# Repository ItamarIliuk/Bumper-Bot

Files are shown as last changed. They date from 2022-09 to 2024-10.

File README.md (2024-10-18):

[][linkedin-url]
[][udemy-url]

<p align="center">
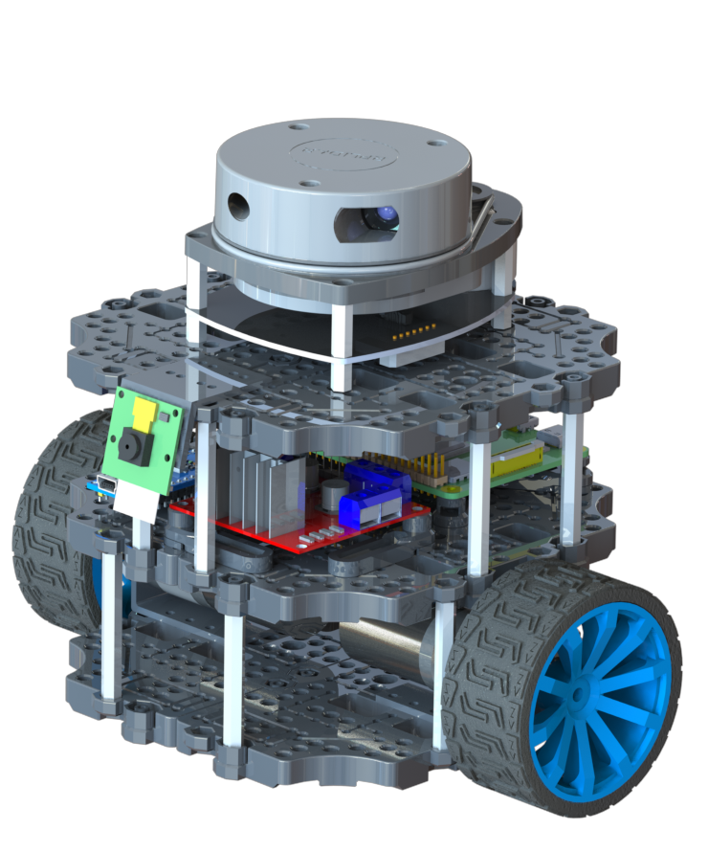
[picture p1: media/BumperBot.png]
  
</p>

Bumperbot is an open-source 3D printed self-driving robot powered by ROS 2. Its simple design and low cost make it an excellent learning platform, featured in the following online courses:
* [Self Driving and ROS 2 - Learn by Doing! Odometry & Control
](https://www.udemy.com/course/self-driving-and-ros-2-learn-by-doing-odometry-control/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)
* [Self Driving and ROS 2 - Learn by Doing! Map & Localization
](https://www.udemy.com/course/self-driving-and-ros-2-learn-by-doing-map-localization/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)

## :robot: Features

- :rocket: [`bumperbot_bringup`](./bumperbot_bringup): Contains launch files that starts all the functionalities of the real or simulated robot.
- :video_game: [`bumperbot_controller`](./bumperbot_controller): Contains the [ROS 2 Control](https://control.ros.org/rolling/index.html) configuration and Hardware interface with the real robot.
- :paperclip: [`bumperbot_cpp_examples`](./bumperbot_cpp_examples): Contains ROS 2 templates for developing with C++.
- :ledger: [`bumperbot_description`](./bumperbot_description): Contains the URDF description of the robot and its Gazebo simulation.
- :battery: [`bumperbot_firmware`](./bumperbot_firmware): Contains the Arduino code for actuating the motors of the real robot.
- :car: [`bumperbot_hardware`](./bumperbot_hardware): Contains the CAD model of the robot along with the STL files for 3D printing the robot.
- :pushpin: [`bumperbot_localization`](./bumperbot_localization): Contains the Odometry calculation using the [robot_localization](https://docs.ros.org/en/melodic/api/robot_localization/html/index.html) package and the Global Localization configuration and launch files for [Nav2 AMCL](https://docs.nav2.org/configuration/packages/configuring-amcl.html).
- :world_map: [`bumperbot_mapping`](./bumperbot_mapping): Contains an implementation of the Mapping with known poses algorithm and the [SLAM Toolbox](https://github.com/SteveMacenski/slam_toolbox) configuration and launch files
- :email: [`bumperbot_msgs`](./bumperbot_msgs/): Contains the definition of new ROS 2 message interfaces.
- :paperclip: [`bumperbot_py_examples`](./bumperbot_py_examples/): Contains ROS 2 templates for developing with Python.
- :hammer_and_pick: [`bumperbot_utils`](./bumperbot_utils/): Contains some utilities and tools.

## :building_construction: Usage

This robot and its simulation can be used with an Ubuntu 22.04 machine running ROS 2 Humble or and Ubuntu 24.04 machine running ROS 2 Jazzy.

### Prerequisites

* Install [Ubuntu 24.04](https://ubuntu.com/download/desktop) or [Ubuntu 22.04](https://releases.ubuntu.com/jammy/) on your PC or in a Virtual Machine.
* Install [ROS 2 Jazzy](https://docs.ros.org/en/jazzy/Installation/Ubuntu-Install-Debians.html) if you are on Ubuntu 24.04. Otherwise, install [ROS 2 Humble](https://docs.ros.org/en/jazzy/Installation/Ubuntu-Install-Debians.html) if you are on Ubuntu 22.04
* Install ROS 2 missing libraries. Some libraries that are used in this project are not in the standard ROS 2 package. Install them with:
* Install [VS Code](https://code.visualstudio.com/) and [Arduino IDE](https://docs.arduino.cc/software/ide-v2/tutorials/getting-started/ide-v2-downloading-and-installing/) on your PC in order to build and load the Arduino code on the device
* Install Python and C++ addistional libraries
```sh
sudo apt-get update && sudo apt-get install -y \
     libserial-dev \
     python3-pip
```

```sh
pip install pyserial
```

### Installation

1. Create a Workspace
```sh
mkdir -p bumperbot/src
```

2. Clone this repo
```sh
cd bumperbot_ws/src
git clone https://github.com/AntoBrandi/Bumper-Bot.git
```

3. Install the dependencies
```sh
cd ..
rosdep install --from-paths src --ignore-src -i -y
```

4. Build the workspace
```sh
colcon build
```

5. Source the ROS Workspace (Use this command in a separate terminal from the one you used to build the workspace)
```sh
. install/setup.bash
```

#### :computer: Simulation

6. Launch all the functionalities for the simulated robot
```sh
ros2 launch bumperbot_bringup simulated_robot.launch.py
```

#### :mechanical_arm: Real Robot

7. Connect the Arduino actuating your robot to your PC and load the [robot_control.ino](./bumperbot_firmware/firmware/robot_control/robot_control.ino) script using the Arduino IDE.

8. Launch all the functionalities for the real robot
```sh
ros2 launch bumperbot_bringup real_robot.launch.py
```

## :selfie: Media

<p align="center">
  Robot Coke
</p>

https://github.com/user-attachments/assets/6a461f72-1dae-4d4d-a8a7-a8a9c1fe127b

https://github.com/user-attachments/assets/a2ec2818-2296-45db-a49b-5c32240cd7d5

https://github.com/user-attachments/assets/122f02ca-ccb7-421f-bb53-b94aba00624b

## :raised_hands: Contributing

Contributions are what make the open source community such an amazing place to be learn, inspire, and create. Any contributions you make are **greatly appreciated**.
Please refer to [CONTRIBUTING](CONTRIBUTING.md) doc.

## :star2: Acknowledgements
* [Turtlebot 3 Burger](https://emanual.robotis.com/docs/en/platform/turtlebot3/overview/)

## :link: Contact

Antonio Brandi - [LinkedIn]([linkedin-url]) - antonio.brandi@outlook.it

Other Projects: [https://github.com/AntoBrandi](https://github.com/AntoBrandi)

[linkedin-shield]: https://img.shields.io/badge/-LinkedIn-black.svg?style=flat-square&logo=linkedin&colorB=555
[linkedin-url]: https://www.linkedin.com/in/antonio-brandi-512166bb/
[udemy-shield]: https://img.shields.io/badge/-Udemy-black.svg?style=flat-square&logo=udemy&colorB=555
[udemy-url]: https://www.udemy.com/course/self-driving-and-ros-2-learn-by-doing-odometry-control/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

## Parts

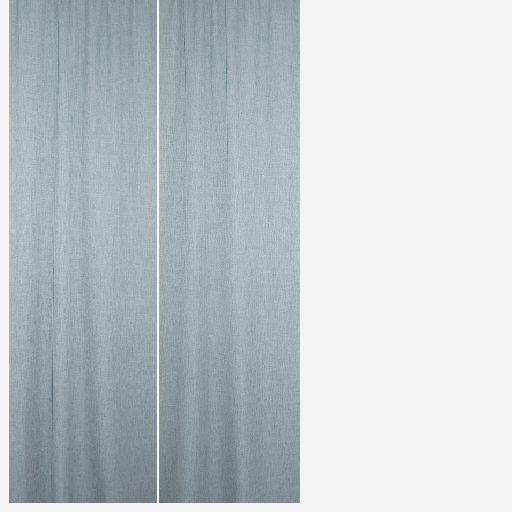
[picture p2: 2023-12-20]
bumperbot_description/models/aws_robomaker_residential_Curtain_01/materials/textures/aws_Curtain_01.png

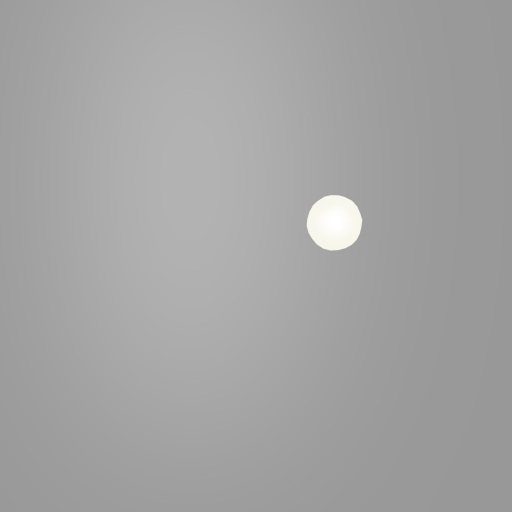
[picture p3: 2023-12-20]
bumperbot_description/models/aws_robomaker_residential_Rangehood_01/materials/textures/aws_Rangehood_01.png

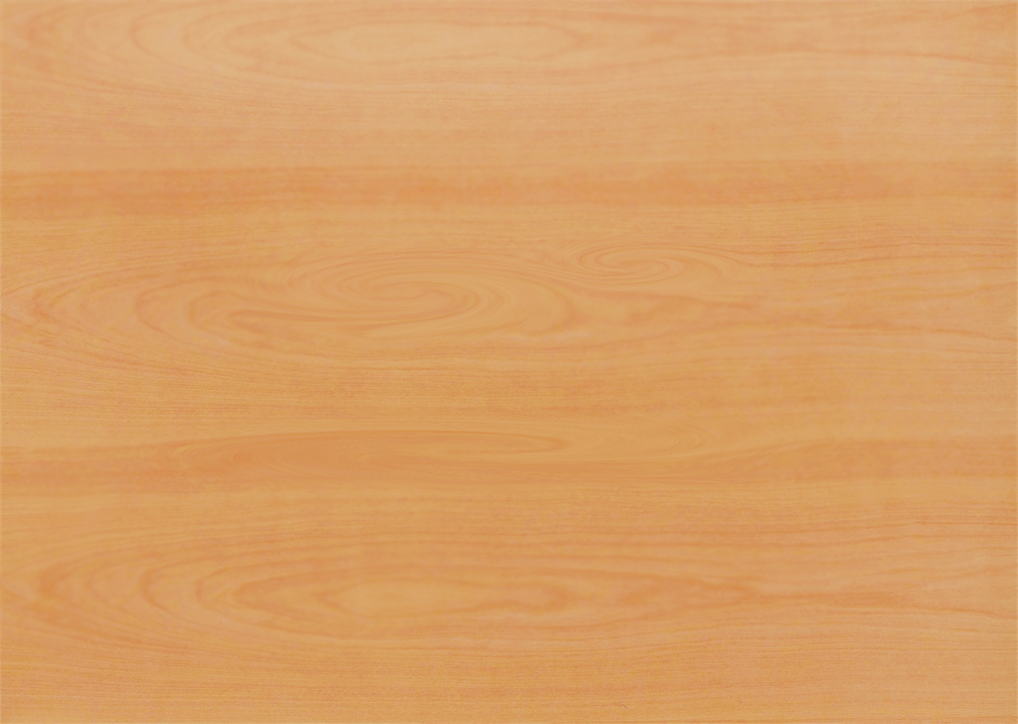
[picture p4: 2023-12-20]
bumperbot_description/models/aws_robomaker_residential_TVCabinet_01/materials/textures/aws_TVCabinet_01.png

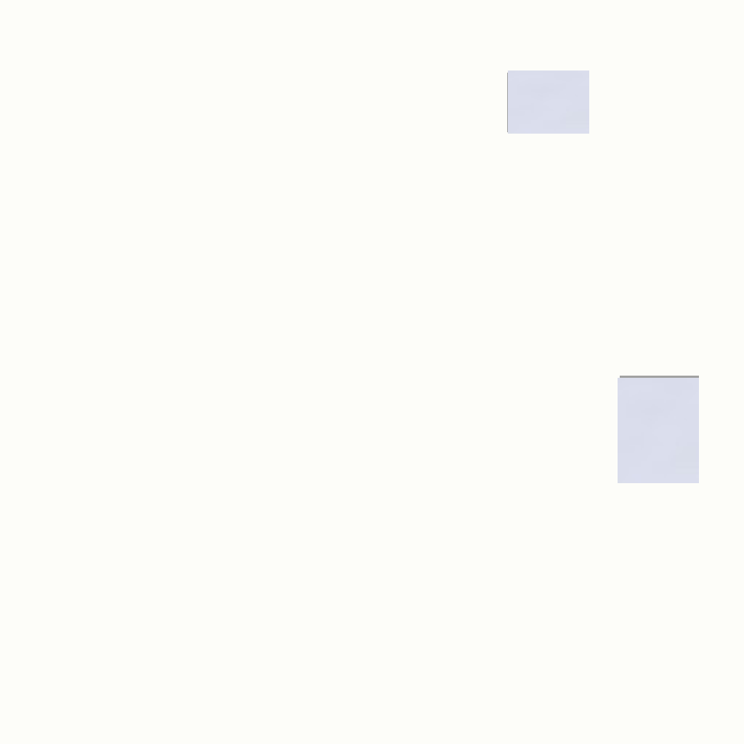
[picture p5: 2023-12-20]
bumperbot_description/models/aws_robomaker_residential_NightStand_01/materials/textures/aws_NightStand_01.png

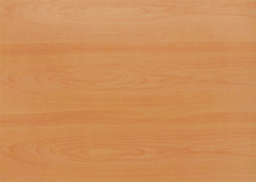
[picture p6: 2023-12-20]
bumperbot_description/models/aws_robomaker_residential_FoldingDoor_02/materials/textures/aws_FoldingDoor_02.png

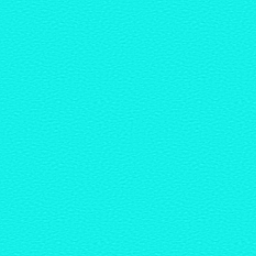
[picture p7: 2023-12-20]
bumperbot_description/models/aws_robomaker_residential_Ball_01/materials/textures/aws_Ball_01.png

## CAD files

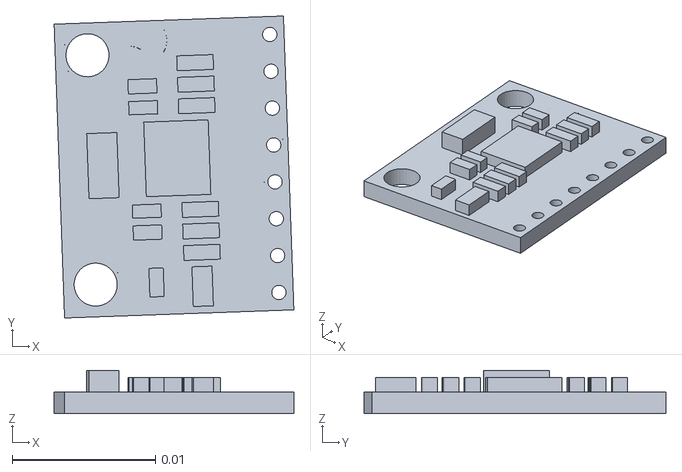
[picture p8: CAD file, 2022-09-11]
bumperbot_description/meshes/imu_link.STL
0.0167 x 0.0211 x 0.003

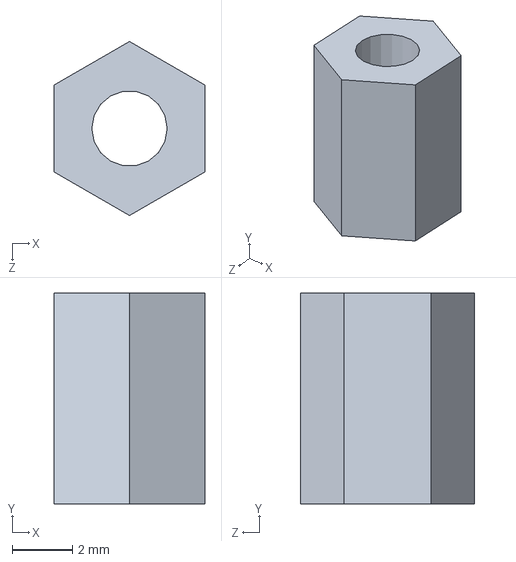
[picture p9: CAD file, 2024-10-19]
bumperbot_hardware/CAD/SUPPORT_HEX_M3_0XL07_FF.SLDPRT
5.00 x 7.00 x 5.77 mm

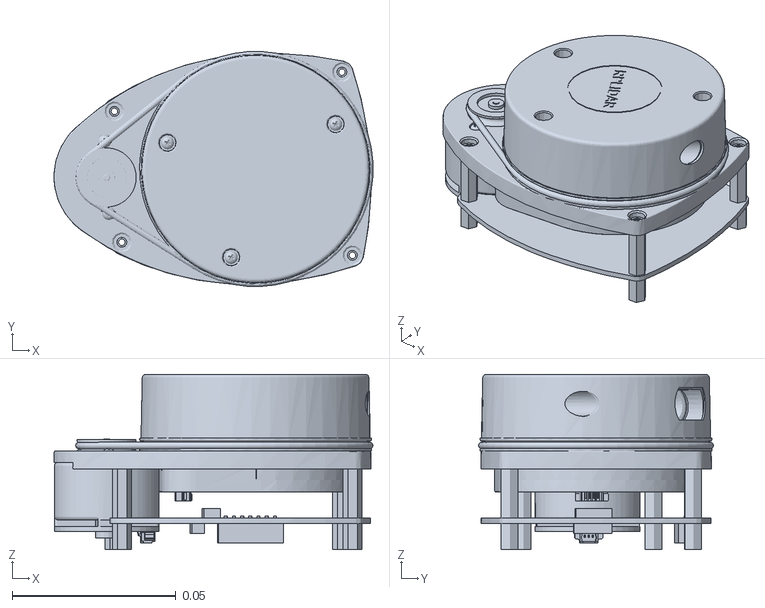
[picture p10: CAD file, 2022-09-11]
bumperbot_description/meshes/laser_link.STL
0.0973 x 0.0717 x 0.0535

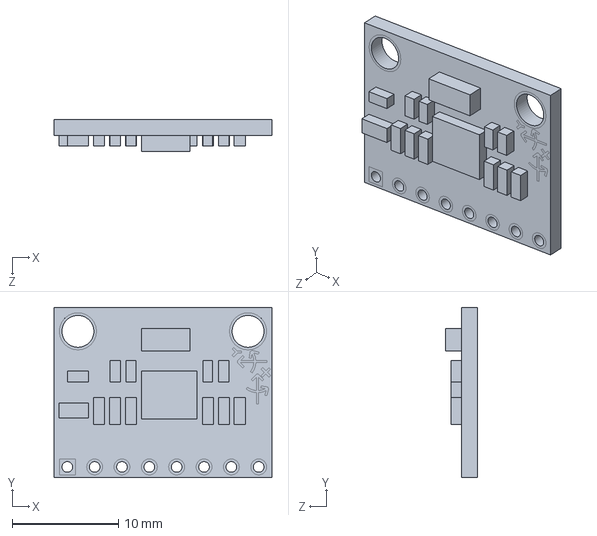
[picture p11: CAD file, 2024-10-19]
bumperbot_hardware/CAD/MPU_6050.SLDPRT
20.5 x 16.0 x 3.00 mm

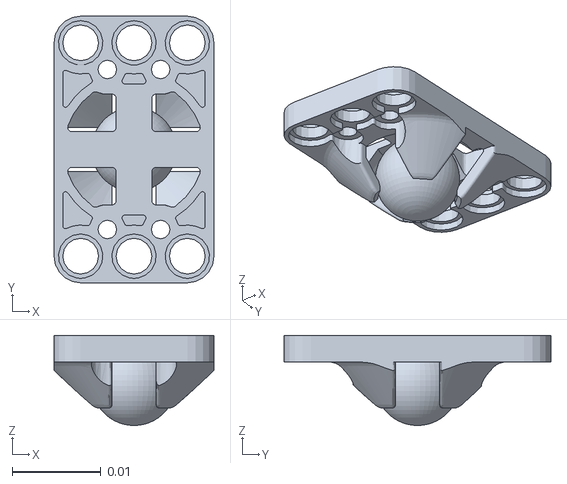
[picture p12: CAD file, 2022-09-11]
bumperbot_description/meshes/caster_front_link.STL
0.018 x 0.03 x 0.0101

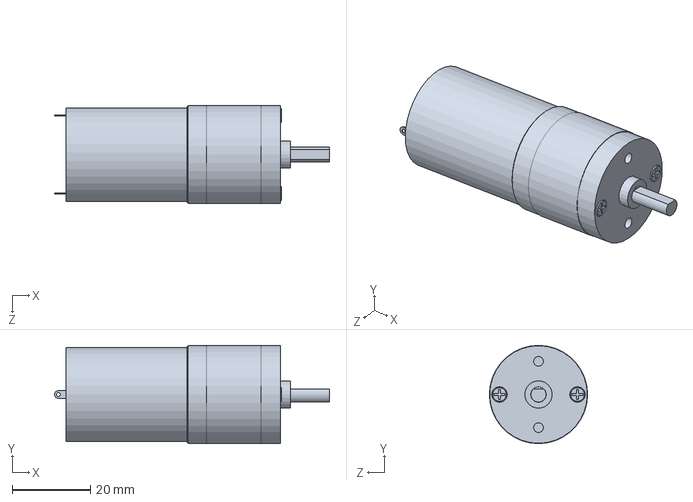
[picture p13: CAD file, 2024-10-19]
bumperbot_hardware/CAD/JGA25-370.SLDPRT
70.5 x 25.2 x 25.2 mm

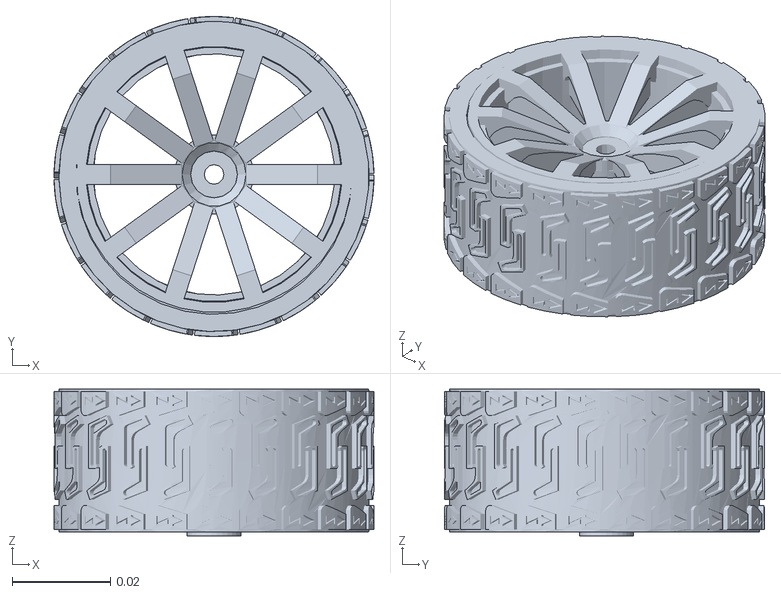
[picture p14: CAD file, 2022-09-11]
bumperbot_description/meshes/wheel_right_link.STL
0.065 x 0.065 x 0.0298

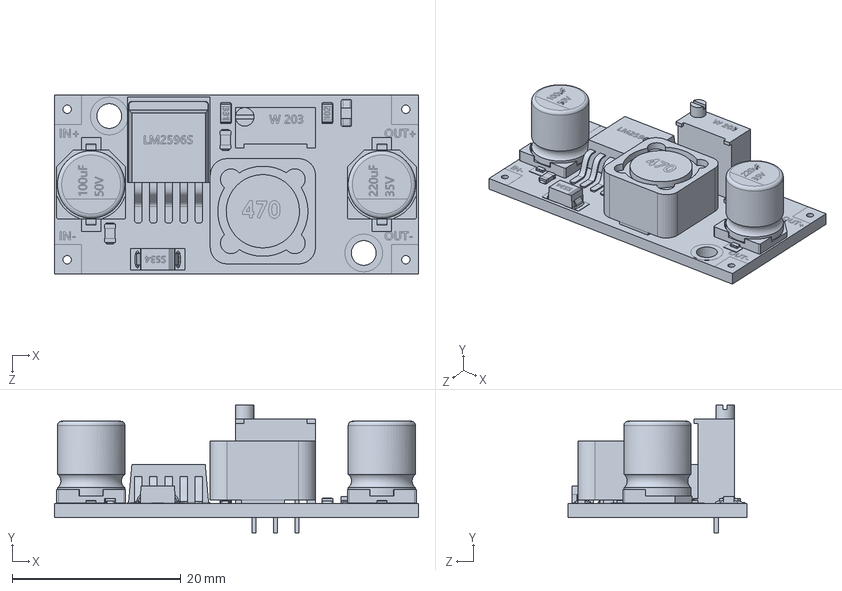
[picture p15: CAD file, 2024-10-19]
bumperbot_hardware/CAD/LM2596_DC_DC.SLDPRT
43.2 x 15.1 x 21.2 mm

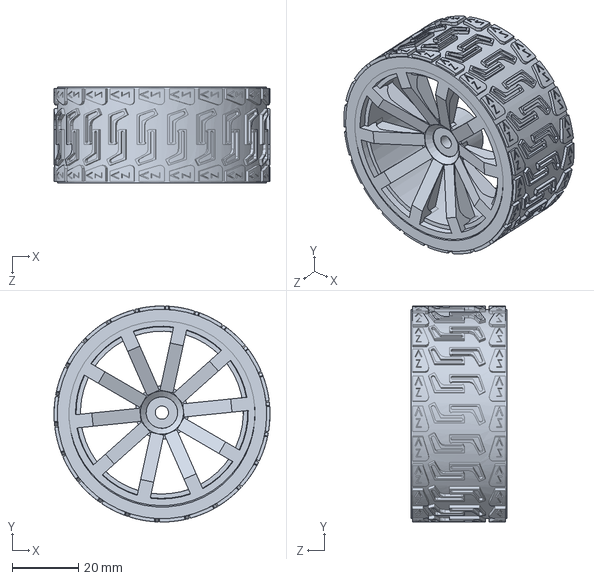
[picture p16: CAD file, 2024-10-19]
bumperbot_hardware/CAD/wheel.SLDPRT
65.0 x 65.0 x 29.0 mm

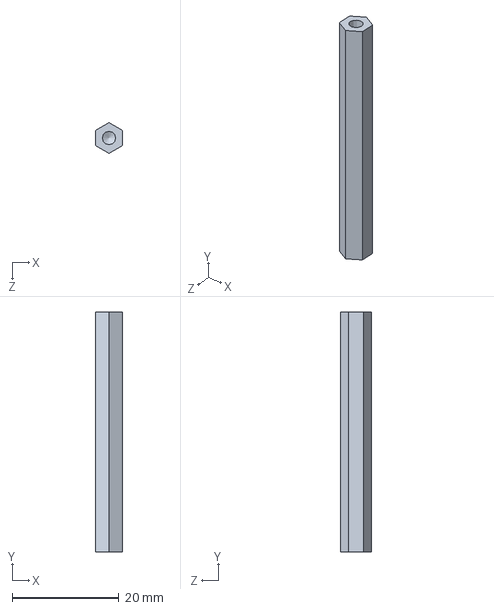
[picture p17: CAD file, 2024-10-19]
bumperbot_hardware/CAD/SUPPORT_HEX_M3_0XL45_FF.SLDPRT
5.00 x 45.0 x 5.77 mm

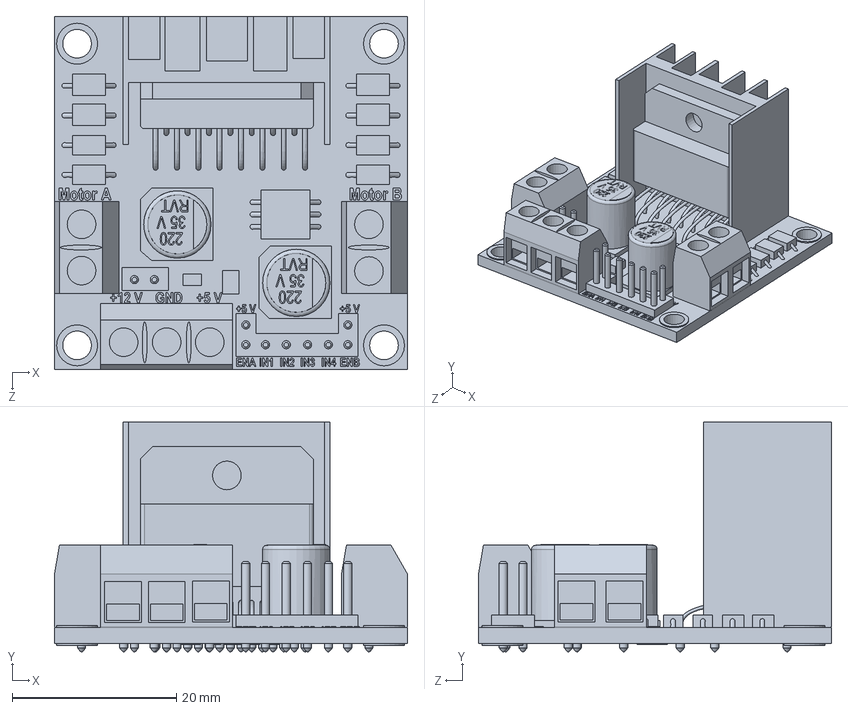
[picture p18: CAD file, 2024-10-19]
bumperbot_hardware/CAD/L298N.SLDPRT
43.0 x 28.0 x 43.0 mm

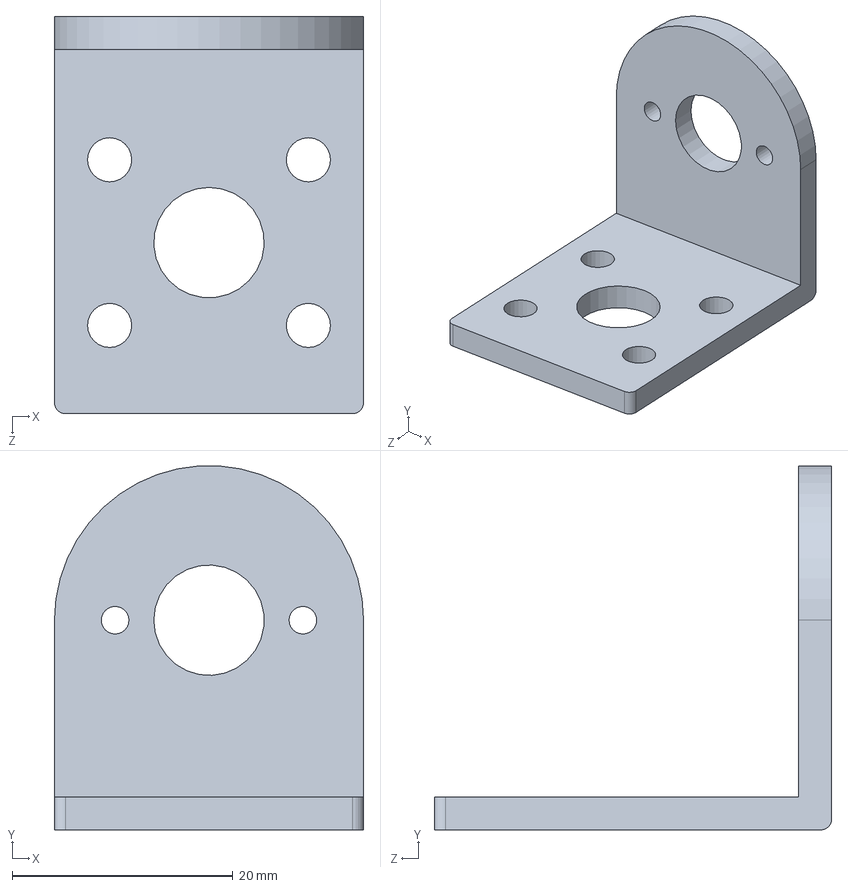
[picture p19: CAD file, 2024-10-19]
bumperbot_hardware/CAD/motor_support.SLDPRT
28.0 x 33.0 x 36.0 mm

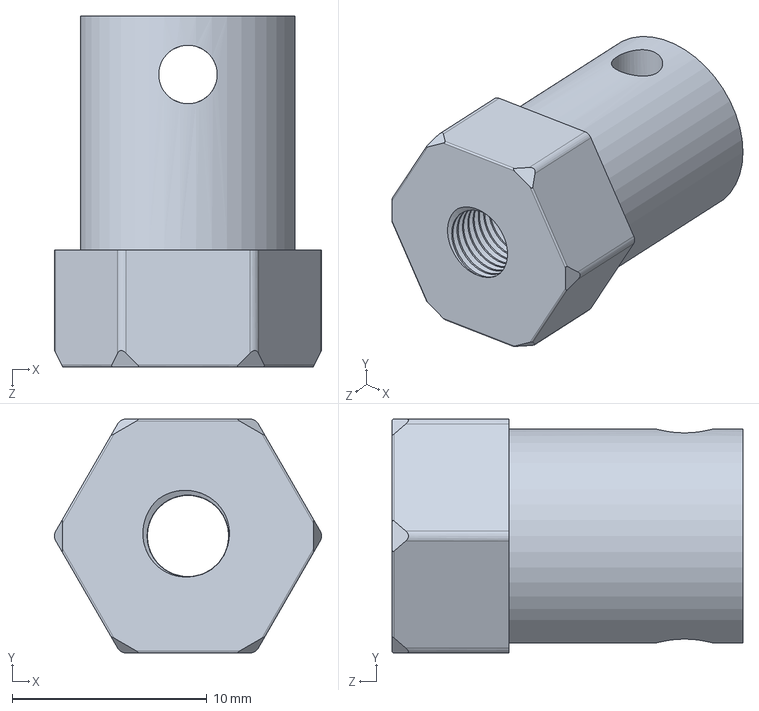
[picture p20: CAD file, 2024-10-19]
bumperbot_hardware/CAD/wheel_motor_adapter.SLDPRT
13.7 x 12.0 x 18.0 mm

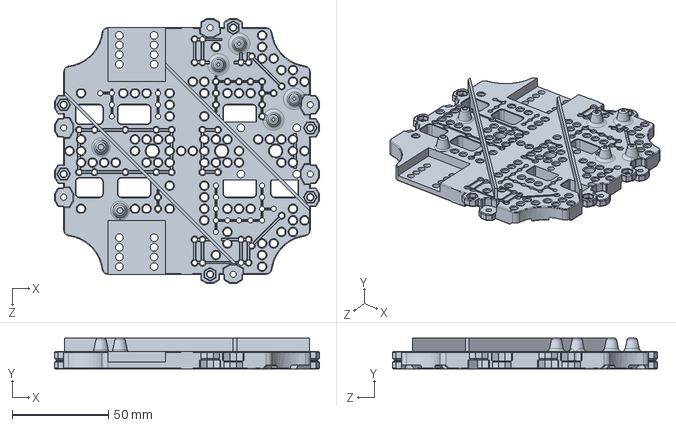
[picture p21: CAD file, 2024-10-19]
bumperbot_hardware/CAD/waffle_base_plate.SLDPRT
137.5 x 16.0 x 137.5 mm

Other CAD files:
bumperbot_description/meshes/caster_rear_link.STL
bumperbot_description/meshes/wheel_left_link.STL
bumperbot_hardware/CAD/TekniRoll.D30mm.TR670-001.SLDPRT
bumperbot_hardware/CAD/battery_pack.SLDPRT

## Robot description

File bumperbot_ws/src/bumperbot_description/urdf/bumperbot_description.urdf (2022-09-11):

<?xml version="1.0" encoding="utf-8"?>
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
<robot name="description">
  <link name="base_link">
    <inertial>
      <origin xyz="-0.00200985226721874 -0.00277448578669132 0.0152338681517865" rpy="0 0 0" />
      <mass value="0.091306007508054" />
      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
    </inertial>
    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
  </link>
  <link name="wheel_right_link">
    <inertial>
      <origin xyz="-3.87574191866857E-05 -0.000675136097099426 0.0137052643928599" rpy="0 0 0" />
      <mass value="0.053008609096452" />
      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
    </inertial>
    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
  </link>
  <joint name="wheel_right_joint" type="continuous">
    <origin xyz="0 -0.07011 0" rpy="-1.5708 -0.95428 3.1416" />
    <parent link="base_link" />
    <child link="wheel_right_link" />
    <axis xyz="0 0 1" />
  </joint>
  <link name="wheel_left_link">
    <inertial>
      <origin xyz="2.9582904985663E-05 -0.00067559856452068 0.0137052653316698" rpy="0 0 0" />
      <mass value="0.0530086043219396" />
      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
    </inertial>
    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
  </link>
  <joint name="wheel_left_joint" type="continuous">
    <origin xyz="0 0.07011 0" rpy="1.5708 0.36986 3.1416" />
    <parent link="base_link" />
    <child link="wheel_left_link" />
    <axis xyz="0 0 1" />
  </joint>
  <link name="caster_front_link">
    <inertial>
      <origin xyz="3.89968128948481E-07 2.40073004694613E-07 0.00219173397061508" rpy="0 0 0" />
      <mass value="1.44379265037903E-06" />
      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
    </inertial>
    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
  </link>
  <joint name="caster_front_joint" type="fixed">
    <origin xyz="0.04755 0 -0.025363" rpy="0 0 0" />
    <parent link="base_link" />
    <child link="caster_front_link" />
    <axis xyz="0 0 0" />
  </joint>
  <link name="caster_rear_link">
    <inertial>
      <origin xyz="3.8996812895542E-07 2.40073004698083E-07 0.00219173397061508" rpy="0 0 0" />
      <mass value="1.44379265037902E-06" />
      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
    </inertial>
    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
  </link>
  <joint name="caster_rear_joint" type="fixed">
    <origin xyz="-0.04755 0 -0.025363" rpy="0 0 0" />
    <parent link="base_link" />
    <child link="caster_rear_link" />
    <axis xyz="0 0 0" />
  </joint>
  <link name="camera_link">
    <inertial>
      <origin xyz="-0.0122943599302166 -9.0517329706663E-07 0.008436849003846" rpy="0 0 0" />
      <mass value="0.0041086489783227" />
      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
    </inertial>
    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
  </link>
  <joint name="camera_joint" type="fixed">
    <origin xyz="0.081561 0 0.067457" rpy="0 -0.23739 0" />
    <parent link="base_link" />
    <child link="camera_link" />
    <axis xyz="0 0 0" />
  </joint>
  <link name="laser_link">
    <inertial>
      <origin xyz="-0.0119457804060619 -0.000381929217680516 -0.0170649378129477" rpy="0 0 0" />
      <mass value="0.073084435549317" />
      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
    </inertial>
    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
  </link>
  <joint name="laser_joint" type="fixed">
    <origin xyz="-0.0050526 -0.0023221 0.1208" rpy="0 0 0" />
    <parent link="base_link" />
    <child link="laser_link" />
    <axis xyz="0 0 0" />
  </joint>
  <link name="imu_link">
    <inertial>
      <origin xyz="-0.00552433659106684 0.000168210391520349 0.000514000497342681" rpy="0 0 0" />
      <mass value="0.000528415362211671" />
      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
    </inertial>
    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
  </link>
  <joint name="imu_joint" type="fixed">
    <origin xyz="0 0 0.069899" rpy="3.1416 0 0" />
    <parent link="base_link" />
    <child link="imu_link" />
    <axis xyz="0 0 0" />
  </joint>
</robot>

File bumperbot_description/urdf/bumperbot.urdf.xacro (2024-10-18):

<?xml version="1.0"?>

<robot name="bumperbot" xmlns:xacro="http://ros.org/wiki/xacro">

  <!-- Start GZ or Ignition depending on ROS 2 Version -->
  <xacro:arg name="is_ignition" default="true"/>

  <!-- Load Simulated or Real Hardware Interfaces -->
  <xacro:arg name="is_sim" default="true"/>

  <!-- Include Gazebo Parameters -->
  <xacro:include filename="$(find bumperbot_description)/urdf/bumperbot_gazebo.xacro" />

  <!-- Include ros2_control Plugins -->
  <xacro:include filename="$(find bumperbot_description)/urdf/bumperbot_ros2_control.xacro" />

  <link name="base_footprint"/>
  
  <link name="base_link">
    <inertial>
      <origin xyz="0 0 0.04" rpy="0.0 0.25 0.3" />
      <mass value="8.2573504e-01"/>
      <inertia ixx="2.2124416e-02" ixy="-1.2294101e-04" ixz="3.4938785e-04" iyy="2.1193702e-02" iyz="-5.0120904e-05" izz="2.0064271e-02" />
    </inertial>
    <visual>
      <origin xyz="0 0 0" rpy="0 0 0" />
      <geometry>
        <mesh filename="package://bumperbot_description/meshes/base_link.STL" />
      </geometry>
      <material name="black"/>
    </visual>
    <collision>
      <origin xyz="0 0 0" rpy="0 0 0" />
      <geometry>
        <mesh filename="package://bumperbot_description/meshes/base_link.STL" />
      </geometry>
    </collision>
  </link>

  <joint name="base_joint" type="fixed">
    <parent link="base_footprint"/>
    <child link="base_link" />
    <origin xyz="0 0 0.033" rpy="0 0 0"/>
  </joint>

  <link name="wheel_right_link">
    <inertial>
      <origin xyz="0 -0.014 0" rpy="0 0 0" />
      <mass value="0.0530086090966721" />
      <inertia ixx="1.88176298336665E-05" ixy="-4.8444933029987E-10" ixz="1.88163708851143E-08" iyy="3.11510738647764E-05" iyz="-6.93560663069607E-11" izz="1.8801969558182E-05" />
    </inertial>
    <visual>
      <origin xyz="0 0 0" rpy="1.57 0 0" />
      <geometry>
        <mesh filename="package://bumperbot_description/meshes/wheel_right_link.STL" />
      </geometry>
      <material name="blue"/>
    </visual>
    <collision>
      <origin xyz="0 -0.015 0" rpy="1.57 0 0" />
      <geometry>
        <sphere radius="0.033"/>
      </geometry>
    </collision>
  </link>

  <joint name="wheel_right_joint" type="continuous">
    <origin xyz="0 -0.0701101849418637 0" rpy="0 0 0" />
    <parent link="base_link" />
    <child link="wheel_right_link" />
    <axis xyz="0 1 0" />
  </joint>
  
  <link name="wheel_left_link">
    <inertial>
      <origin xyz="0 0.014 0" rpy="0 0 0" />
      <mass value="0.0530086043217644" />
      <inertia ixx="1.8792911368909E-05" ixy="3.31256392204584E-10" ixz="-1.14082001662767E-08" iyy="3.11510738759073E-05" iyz="-3.60499245082192E-10" izz="1.88266886146847E-05" />
    </inertial>
    <visual>
      <origin xyz="0 0 0" rpy="-1.57 0 0" />
      <geometry>
        <mesh filename="package://bumperbot_description/meshes/wheel_left_link.STL" />
      </geometry>
      <material name="blue"/>
    </visual>
    <collision>
      <origin xyz="0 0.015 0" rpy="-1.57 0 0" />
      <geometry>
        <sphere radius="0.033"/>
      </geometry>
    </collision>
  </link>

  <joint name="wheel_left_joint" type="continuous">
    <origin xyz="0 0.0701101849418642 0" rpy="0 0 0" />
    <parent link="base_link" />
    <child link="wheel_left_link" />
    <axis xyz="0 1 0" />
  </joint>

  <link name="caster_front_link">
    <inertial>
      <origin xyz="3.89968128948481E-07 2.40073004698083E-07 0.00219173397061506" rpy="0 0 0" />
      <mass value="1.44379265037903E-06" />
      <inertia ixx="7.23075276010246E-11" ixy="-6.10956883467859E-16" ixz="2.22849693525031E-15" iyy="3.8713793085917E-11" iyz="2.93909858781952E-15" izz="1.00967486676306E-10" />
    </inertial>
    <visual>
      <origin xyz="0 0 0" rpy="0 0 0" />
      <geometry>
        <mesh filename="package://bumperbot_description/meshes/caster_front_link.STL" />
      </geometry>
      <material name="silver"/>
    </visual>
    <collision>
      <origin xyz="0 0 0" rpy="0 0 0" />
      <geometry>
        <sphere radius="0.005"/>
      </geometry>
    </collision>
  </link>

  <joint name="caster_front_joint" type="fixed">
    <origin xyz="0.04755 0 -0.0275" rpy="0 0 0" />
    <parent link="base_link" />
    <child link="caster_front_link" />
    <axis xyz="0 0 0" />
  </joint>
  
  <link name="caster_rear_link">
    <inertial>
      <origin xyz="3.8996812895542E-07 2.40073004698083E-07 0.00219173397061509" rpy="0 0 0" />
      <mass value="1.44379265037902E-06" />
      <inertia ixx="7.23075276010246E-11" ixy="-6.10956872363424E-16" ixz="2.22849693527207E-15" iyy="3.87137930859167E-11" iyz="2.939098587861E-15" izz="1.00967486676306E-10" />
    </inertial>
    <visual>
      <origin xyz="0 0 0" rpy="0 0 0" />
      <geometry>
        <mesh filename="package://bumperbot_description/meshes/caster_rear_link.STL" />
      </geometry>
      <material name="silver"/>
    </visual>
    <collision>
      <origin xyz="0 0 0" rpy="0 0 0" />
      <geometry>
        <sphere radius="0.005"/>
      </geometry>
    </collision>
  </link>

  <joint name="caster_rear_joint" type="fixed">
    <origin xyz="-0.04755 0 -0.0275" rpy="0 0 0" />
    <parent link="base_link" />
    <child link="caster_rear_link" />
    <axis xyz="0 0 0" />
  </joint>

  <link name="imu_link">
    <inertial>
      <origin xyz="-0.00552433659106688 0.000168210391520346 0.000514000497342681" rpy="0 0 0" />
      <mass value="0.000528415362211671" />
      <inertia ixx="1.46176048428261E-08" ixy="1.40015117949421E-10" ixz="-1.99633872937403E-12" iyy="8.59662482954888E-09" iyz="7.52375112767959E-12" izz="2.30279421279312E-08" />
    </inertial>
    <visual>
      <origin xyz="0 0 0" rpy="0 0 0" />
      <geometry>
        <mesh filename="package://bumperbot_description/meshes/imu_link.STL" />
      </geometry>
      <material name="blue"/>
    </visual>
    <collision>
      <origin xyz="0 0 0" rpy="0 0 0" />
      <geometry>
        <mesh filename="package://bumperbot_description/meshes/imu_link.STL" />
      </geometry>
    </collision>
  </link>
  
  <joint name="imu_joint" type="fixed">
    <origin xyz="0 0 0.0698986241758014" rpy="0 0 0" />
    <parent link="base_link" />
    <child link="imu_link" />
    <axis xyz="0 0 0" />
  </joint>

  <link name="laser_link">
    <inertial>
      <origin xyz="-0.011945780406062 -0.000381929217680526 -0.0170649378129477" rpy="0 0 0" />
      <mass value="0.073084435549317" />
      <inertia ixx="1.96074931730795E-05" ixy="-3.62091076640009E-07" ixz="4.28230084046735E-07" iyy="2.40983835136327E-05" iyz="1.50180909250652E-08" izz="4.14184164228595E-05" />
    </inertial>
    <visual>
      <origin xyz="0 0 0" rpy="0 0 0" />
      <geometry>
        <mesh filename="package://bumperbot_description/meshes/laser_link.STL" />
      </geometry>
      <material name="dark_grey"/>
    </visual>
    <collision>
      <origin xyz="0 0 0" rpy="0 0 0" />
      <geometry>
        <mesh filename="package://bumperbot_description/meshes/laser_link.STL" />
      </geometry>
    </collision>
  </link>

  <joint name="laser_joint" type="fixed">
    <origin xyz="-0.0050526 -0.0023221 0.1208" rpy="0 0 3.14" />
    <parent link="base_link" />
    <child link="laser_link" />
    <axis xyz="0 0 0" />
  </joint>

  <material name="blue">
    <color rgba="0 0 1 1"/>
  </material>
  <material name="black">
    <color rgba="0 0 0 1"/>
  </material>
  <material name="silver">
    <color rgba="0.79 0.82 0.93 1"/>
  </material>
  <material name="dark_grey">
    <color rgba="0.3 0.3 0.3 1"/>
  </material>

</robot>

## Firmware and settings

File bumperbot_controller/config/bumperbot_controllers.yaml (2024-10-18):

controller_manager:
  ros__parameters:
    update_rate: 100 # Hz

    bumperbot_controller:
      type: diff_drive_controller/DiffDriveController

    joint_state_broadcaster:
      type: joint_state_broadcaster/JointStateBroadcaster

    simple_velocity_controller:
      type: velocity_controllers/JointGroupVelocityController


bumperbot_controller:
  ros__parameters:
    type        : diff_drive_controller/DiffDriveController
    use_stamped_vel: true
    left_wheel_names  : ['wheel_left_joint']
    right_wheel_names : ['wheel_right_joint']

    publish_rate: 50.0               # default: 50
    pose_covariance_diagonal : [0.001, 0.001, 1.0e-3, 1.0e-3, 1.0e-3, 0.01]
    twist_covariance_diagonal: [0.001, 0.001, 1.0e-3, 1.0e-3, 1.0e-3, 0.01]

    wheel_separation : 0.17
    wheel_radius : 0.033

    wheel_separation_multiplier: 1.0
    left_wheel_radius_multiplier: 1.0
    right_wheel_radius_multiplier: 1.0

    # Velocity commands timeout [s], default 0.5
    cmd_vel_timeout: 0.5

    # Base frame_id
    base_frame_id: base_footprint #default: base_link

    # Publish limited velocity
    publish_limited_velocity: true

    # Publish wheel data
    publish_wheel_data: true

    # Publish to TF directly or not
    enable_odom_tf: true

    # Velocity and acceleration limits
    # Whenever a min_* is unspecified, default to -max_*
    linear:
      x:
        has_velocity_limits    : true
        max_velocity           : 0.7  # m/s
        min_velocity           : -0.7 # m/s
        has_acceleration_limits: true
        max_acceleration       : 0.7  # m/s^2
        min_acceleration       : -0.7 # m/s^2
        has_jerk_limits        : false
        max_jerk               : 5.0  # m/s^3
    angular:
      z:
        has_velocity_limits    : true
        max_velocity           : 8.5  # rad/s
        min_velocity           : -8.5  # rad/s
        has_acceleration_limits: true
        max_acceleration       : 5.0  # rad/s^2
        min_acceleration       : -5.0   # rad/s^2
        has_jerk_limits        : false
        max_jerk               : 2.5  # rad/s^3


simple_velocity_controller:
  ros__parameters:
    joints:
      - wheel_left_joint
      - wheel_right_joint

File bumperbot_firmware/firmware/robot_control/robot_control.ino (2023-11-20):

#include <PID_v1.h>

// L298N H-Bridge Connection PINs
#define L298N_enA 9  // PWM
#define L298N_enB 11  // PWM
#define L298N_in4 8  // Dir Motor B
#define L298N_in3 7  // Dir Motor B
#define L298N_in2 13  // Dir Motor A
#define L298N_in1 12  // Dir Motor A

// Wheel Encoders Connection PINs
#define right_encoder_phaseA 3  // Interrupt 
#define right_encoder_phaseB 5  
#define left_encoder_phaseA 2   // Interrupt
#define left_encoder_phaseB 4

// Encoders
unsigned int right_encoder_counter = 0;
unsigned int left_encoder_counter = 0;
String right_wheel_sign = "p";  // 'p' = positive, 'n' = negative
String left_wheel_sign = "p";  // 'p' = positive, 'n' = negative
unsigned long last_millis = 0;
const unsigned long interval = 100;

// Interpret Serial Messages
bool is_right_wheel_cmd = false;
bool is_left_wheel_cmd = false;
bool is_right_wheel_forward = true;
bool is_left_wheel_forward = true;
char value[] = "00.00";
uint8_t value_idx = 0;
bool is_cmd_complete = false;

// PID
// Setpoint - Desired
double right_wheel_cmd_vel = 0.0;     // rad/s
double left_wheel_cmd_vel = 0.0;      // rad/s
// Input - Measurement
double right_wheel_meas_vel = 0.0;    // rad/s
double left_wheel_meas_vel = 0.0;     // rad/s
// Output - Command
double right_wheel_cmd = 0.0;             // 0-255
double left_wheel_cmd = 0.0;              // 0-255
// Tuning
double Kp_r = 11.5;
double Ki_r = 7.5;
double Kd_r = 0.1;
double Kp_l = 12.8;
double Ki_l = 8.3;
double Kd_l = 0.1;
// Controller
PID rightMotor(&right_wheel_meas_vel, &right_wheel_cmd, &right_wheel_cmd_vel, Kp_r, Ki_r, Kd_r, DIRECT);
PID leftMotor(&left_wheel_meas_vel, &left_wheel_cmd, &left_wheel_cmd_vel, Kp_l, Ki_l, Kd_l, DIRECT);

void setup() {
  // Init L298N H-Bridge Connection PINs
  pinMode(L298N_enA, OUTPUT);
  pinMode(L298N_enB, OUTPUT);
  pinMode(L298N_in1, OUTPUT);
  pinMode(L298N_in2, OUTPUT);
  pinMode(L298N_in3, OUTPUT);
  pinMode(L298N_in4, OUTPUT);

  // Set Motor Rotation Direction
  digitalWrite(L298N_in1, HIGH);
  digitalWrite(L298N_in2, LOW);
  digitalWrite(L298N_in3, HIGH);
  digitalWrite(L298N_in4, LOW);

  rightMotor.SetMode(AUTOMATIC);
  leftMotor.SetMode(AUTOMATIC);
  Serial.begin(115200);

  // Init encoders
  pinMode(right_encoder_phaseB, INPUT);
  pinMode(left_encoder_phaseB, INPUT);
  // Set Callback for Wheel Encoders Pulse
  attachInterrupt(digitalPinToInterrupt(right_encoder_phaseA), rightEncoderCallback, RISING);
  attachInterrupt(digitalPinToInterrupt(left_encoder_phaseA), leftEncoderCallback, RISING);
}

void loop() {
  // Read and Interpret Wheel Velocity Commands
  if (Serial.available())
  {
    char chr = Serial.read();
    // Right Wheel Motor
    if(chr == 'r')
    {
      is_right_wheel_cmd = true;
      is_left_wheel_cmd = false;
      value_idx = 0;
      is_cmd_complete = false;
    }
    // Left Wheel Mo tor
    else if(chr == 'l')
    {
      is_right_wheel_cmd = false;
      is_left_wheel_cmd = true;
      value_idx = 0;
    }
    // Positive direction
    else if(chr == 'p')
    {
      if(is_right_wheel_cmd && !is_right_wheel_forward)
      {
        // change the direction of the rotation
        digitalWrite(L298N_in1, HIGH - digitalRead(L298N_in1));
        digitalWrite(L298N_in2, HIGH - digitalRead(L298N_in2));
        is_right_wheel_forward = true;
      }
      else if(is_left_wheel_cmd && !is_left_wheel_forward)
      {
        // change the direction of the rotation
        digitalWrite(L298N_in3, HIGH - digitalRead(L298N_in3));
        digitalWrite(L298N_in4, HIGH - digitalRead(L298N_in4));
        is_left_wheel_forward = true;
      }
    }
    // Negative direction
    else if(chr == 'n')
    {
      if(is_right_wheel_cmd && is_right_wheel_forward)
      {
        // change the direction of the rotation
        digitalWrite(L298N_in1, HIGH - digitalRead(L298N_in1));
        digitalWrite(L298N_in2, HIGH - digitalRead(L298N_in2));
        is_right_wheel_forward = false;
      }
      else if(is_left_wheel_cmd && is_left_wheel_forward)
      {
        // change the direction of the rotation
        digitalWrite(L298N_in3, HIGH - digitalRead(L298N_in3));
        digitalWrite(L298N_in4, HIGH - digitalRead(L298N_in4));
        is_left_wheel_forward = false;
      }
    }
    // Separator
    else if(chr == ',')
    {
      if(is_right_wheel_cmd)
      {
        right_wheel_cmd_vel = atof(value);
      }
      else if(is_left_wheel_cmd)
      {
        left_wheel_cmd_vel = atof(value);
        is_cmd_complete = true;
      }
      // Reset for next command
      value_idx = 0;
      value[0] = '0';
      value[1] = '0';
      value[2] = '.';
      value[3] = '0';
      value[4] = '0';
      value[5] = '\0';
    }
    // Command Value
    else
    {
      if(value_idx < 5)
      {
        value[value_idx] = chr;
        value_idx++;
      }
    }
  }

  // Encoder
  unsigned long current_millis = millis();
  if(current_millis - last_millis >= interval)
  {
    right_wheel_meas_vel = (10 * right_encoder_counter * (60.0/385.0)) * 0.10472;
    left_wheel_meas_vel = (10 * left_encoder_counter * (60.0/385.0)) * 0.10472;
    
    rightMotor.Compute();
    leftMotor.Compute();

    // Ignore commands smaller than inertia
    if(right_wheel_cmd_vel == 0.0)
    {
      right_wheel_cmd = 0.0;
    }
    if(left_wheel_cmd_vel == 0.0)
    {
      left_wheel_cmd = 0.0;
    }

    String encoder_read = "r" + right_wheel_sign + String(right_wheel_meas_vel) + ",l" + left_wheel_sign + String(left_wheel_meas_vel) + ",";
    Serial.println(encoder_read);
    last_millis = current_millis;
    right_encoder_counter = 0;
    left_encoder_counter = 0;

    analogWrite(L298N_enA, right_wheel_cmd);
    analogWrite(L298N_enB, left_wheel_cmd);
  }
}

// New pulse from Right Wheel Encoder
void rightEncoderCallback()
{
  if(digitalRead(right_encoder_phaseB) == HIGH)
  {
    right_wheel_sign = "p";
  }
  else
  {
    right_wheel_sign = "n";
  }
  right_encoder_counter++;
}

// New pulse from Left Wheel Encoder
void leftEncoderCallback()
{
  if(digitalRead(left_encoder_phaseB) == HIGH)
  {
    left_wheel_sign = "n";
  }
  else
  {
    left_wheel_sign = "p";
  }
  left_encoder_counter++;
}

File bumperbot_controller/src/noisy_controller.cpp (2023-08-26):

#include "bumperbot_controller/noisy_controller.hpp"
#include <tf2/LinearMath/Quaternion.h>
#include <random>


using std::placeholders::_1;


NoisyController::NoisyController(const std::string& name)
                                  : Node(name)
                                  , left_wheel_prev_pos_(0.0)
                                  , right_wheel_prev_pos_(0.0)
                                  , x_(0.0)
                                  , y_(0.0)
                                  , theta_(0.0)
{
    declare_parameter("wheel_radius", 0.033);
    declare_parameter("wheel_separation", 0.17);
    wheel_radius_ = get_parameter("wheel_radius").as_double();
    wheel_separation_ = get_parameter("wheel_separation").as_double();
    RCLCPP_INFO_STREAM(get_logger(), "Using wheel radius " << wheel_radius_);
    RCLCPP_INFO_STREAM(get_logger(), "Using wheel separation " << wheel_separation_);

    joint_sub_ = create_subscription<sensor_msgs::msg::JointState>("/joint_states", 10, std::bind(&NoisyController::jointCallback, this, _1));
    odom_pub_ = create_publisher<nav_msgs::msg::Odometry>("/bumperbot_controller/odom_noisy", 10);

    // Fill the Odometry message with invariant parameters
    odom_msg_.header.frame_id = "odom";
    odom_msg_.child_frame_id = "base_footprint_ekf";
    odom_msg_.pose.pose.orientation.x = 0.0;
    odom_msg_.pose.pose.orientation.y = 0.0;
    odom_msg_.pose.pose.orientation.z = 0.0;
    odom_msg_.pose.pose.orientation.w = 1.0;

    transform_broadcaster_ = std::make_unique<tf2_ros::TransformBroadcaster>(*this);
    transform_stamped_.header.frame_id = "odom";
    transform_stamped_.child_frame_id = "base_footprint_noisy";

    prev_time_ = get_clock()->now();
}


void NoisyController::jointCallback(const sensor_msgs::msg::JointState &state)
{
    // Implements the inverse differential kinematic model
    // Given the position of the wheels, calculates their velocities
    // then calculates the velocity of the robot wrt the robot frame
    // and then converts it in the global frame and publishes the TF

    // Add noise to wheel readings
    unsigned seed = std::chrono::system_clock::now().time_since_epoch().count();
    std::default_random_engine noise_generator(seed);
    std::normal_distribution<double> left_encoder_noise(0.0, 0.005);
    std::normal_distribution<double> right_encoder_noise(0.0, 0.005);

    double wheel_encoder_left = state.position.at(1) + left_encoder_noise(noise_generator);
    double wheel_encoder_right = state.position.at(0) + right_encoder_noise(noise_generator);

    double dp_left = wheel_encoder_left - left_wheel_prev_pos_;
    double dp_right = wheel_encoder_right - right_wheel_prev_pos_;
    rclcpp::Time msg_time = state.header.stamp;
    rclcpp::Duration dt = msg_time - prev_time_;

    // Actualize the prev pose for the next itheration
    left_wheel_prev_pos_ = state.position.at(1);
    right_wheel_prev_pos_ = state.position.at(0);
    prev_time_ = state.header.stamp;

    // Calculate the rotational speed of each wheel
    double fi_left = dp_left / dt.seconds();
    double fi_right = dp_right / dt.seconds();

    // Calculate the linear and angular velocity
    double linear = (wheel_radius_ * fi_right + wheel_radius_ * fi_left) / 2;
    double angular = (wheel_radius_ * fi_right - wheel_radius_ * fi_left) / wheel_separation_;

    // Calculate the position increment
    double d_s = (wheel_radius_ * dp_right + wheel_radius_ * dp_left) / 2;
    double d_theta = (wheel_radius_ * dp_right - wheel_radius_ * dp_left) / wheel_separation_;
    theta_ += d_theta;
    x_ += d_s * cos(theta_);
    y_ += d_s * sin(theta_);

    // Compose and publish the odom message
    tf2::Quaternion q;
    q.setRPY(0, 0, theta_);
    odom_msg_.header.stamp = get_clock()->now();
    odom_msg_.pose.pose.position.x = x_;
    odom_msg_.pose.pose.position.y = y_;
    odom_msg_.pose.pose.orientation.x = q.getX();
    odom_msg_.pose.pose.orientation.y = q.getY();
    odom_msg_.pose.pose.orientation.z = q.getZ();
    odom_msg_.pose.pose.orientation.w = q.getW();
    odom_msg_.twist.twist.linear.x = linear;
    odom_msg_.twist.twist.angular.z = angular;
    odom_pub_->publish(odom_msg_);

    // TF
    transform_stamped_.transform.translation.x = x_;
    transform_stamped_.transform.translation.y = y_;
    transform_stamped_.transform.rotation.x = q.getX();
    transform_stamped_.transform.rotation.y = q.getY();
    transform_stamped_.transform.rotation.z = q.getZ();
    transform_stamped_.transform.rotation.w = q.getW();
    transform_stamped_.header.stamp = get_clock()->now();
    transform_broadcaster_->sendTransform(transform_stamped_);
}


int main(int argc, char* argv[])
{
  rclcpp::init(argc, argv);
  auto node = std::make_shared<NoisyController>("noisy_controller");
  rclcpp::spin(node);
  rclcpp::shutdown();
  return 0;
}

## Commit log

2022-09-11 added CAD models and URDF
    [JGA25-370.SLDPRT, L298N.SLDPRT, MPU_6050.SLDPRT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]
2022-09-11 added rviz config
    [bumperbot_description.urdf]
2022-09-11 updated description
    [JGA25-370.SLDPRT, bumperbot_description.urdf, camera_link.SLDASM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]
2022-09-11 Fix URDF frames
    [bumperbot_description.urdf]
2022-09-14 updated wheel rotation axis
    [bumperbot.urdf]
2022-09-14 updated wheels
    [bumperbot.urdf]
2022-09-14 added gazebo properties and controller
    [bumperbot.urdf, wheel_controller.yaml]
2022-09-16 simualtion and controller
    [bumperbot.urdf, bumperbot.urdf.xacro, bumperbot_gazebo.xacro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]
2022-09-16 removed jerk limits for motion stability
    [wheel_controller.yaml]
2022-09-18 added c++ template
    [simple_controller.yaml]
2022-09-19 added odometry model
2022-09-20 added position to odometry model
2022-09-21 finetuning gazebo model
    [bumperbot.urdf.xacro, bumperbot_gazebo.xacro]
2022-09-23 finetuning controller parameters
    [bumperbot.urdf.xacro, bumperbot_gazebo.xacro, wheel_controller.yaml]
2022-09-24 unified topic names between controllers
    [wheel_controller.yaml]
2022-09-24 added IMU and localization package
    [bumperbot_gazebo.xacro]
2022-09-25 added tf examples
    [bumperbot_gazebo.xacro]
2022-09-27 added noise to odometry model
2022-09-28 implemented kalman filter
    [bumperbot_gazebo.xacro]
2022-10-01 added kalman filter for angular position
    [bumperbot_gazebo.xacro]
2022-10-02 added kalman filter in c++
2022-10-02 added configuration for robot_localization package
    [wheel_controller.yaml]
2022-10-03 changing kalman filter for velocities
2022-10-22 added mapping and localization
    [bumperbot_gazebo.xacro]
2023-08-24 init ROS 2 migration
    [bumperbot.urdf.xacro, bumperbot_controller.yaml, bumperbot_controllers.yaml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]
2023-08-25 added examples and default controller
    [bumperbot_controller.yaml, bumperbot_controllers.yaml, bumperbot_gazebo.xacro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]
2023-08-25 added controllers
    [bumperbot.urdf.xacro, bumperbot_gazebo.xacro, bumperbot_ros2_control.xacro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]
2023-08-25 added cpp kalman filter
2023-08-26 added imu republisher node and kalman filter
    [bumperbot.urdf.xacro, bumperbot_gazebo.xacro]
2023-08-27 added delay for imu republisher to work
2023-08-28 small fixes and formatting
    [bumperbot_ros2_control.xacro]
2023-10-21 uniform with course lessons
    [bumperbot.urdf.xacro, bumperbot_gazebo.xacro, bumperbot_ros2_control.xacro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]
2023-10-22 added interface with real hardware
    [bumperbot.urdf.xacro, bumperbot_ros2_control.xacro]
2023-10-25 fixed hardware interface
    [bumperbot_controllers.yaml, bumperbot_ros2_control.xacro]
2023-11-06 using hardware interface for real robot
    [bumperbot_controllers.yaml]
2023-11-11 added bringup
    [bumperbot_controllers.yaml]
2023-11-18 using arduino nano and PID controller
    [bumperbot_controllers.yaml]
2023-11-19 encoder measure rotation direction
    [bumperbot_controllers.yaml]
2023-11-20 removed logs and increased accelerations
    [bumperbot_controllers.yaml]
2023-11-23 fixed simple motor control code
    [simple_motor_control.ino]
2023-12-17 gazebo world, odometry motion model
    [bumperbot.urdf.xacro, bumperbot_gazebo.xacro, laser_link.STL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]
2023-12-20 first odometry model version
2023-12-21 using twist_mux
    [bumperbot_controllers.yaml]
2023-12-23 safety stop using velocity zones
    [bumperbot_controllers.yaml]
2023-12-26 added odometry motion model python
2024-01-05 init mapping with known poses
    [bumperbot.urdf.xacro, bumperbot_controllers.yaml]
2024-06-25 updated code on lessons
    [bumperbot_controllers.yaml, bumperbot_gazebo.xacro, model-1_2.sdf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]
2024-10-18 update with lessons
    [JGA25-370.SLDPRT, L298N.SLDPRT, MPU_6050.SLDPRT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]
2024-10-19 robot CAD mark.2
    [JGA25-370.SLDPRT, L298N.SLDPRT, LM2596_DC_DC.SLDPRT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]
2025-01-16 ajuste no urdf
